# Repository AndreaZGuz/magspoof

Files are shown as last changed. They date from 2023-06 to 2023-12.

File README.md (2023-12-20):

# MagSpoof By Electronic Cats

# What is MagSpoof?

**MagSpoof by Electronic Cats** is a device that can spoof/emulate any magnetic stripe or credit card. It can work "wirelessly", even on **standard magstripe/credit card readers**, by generating a strong electromagnetic field that emulates a traditional magnetic stripe card.

* Allows you to store all of your credit cards and magstripes in one device
* Works on traditional magstripe readers **wirelessly** (no NFC/RFID required)
* Can **disable** Chip-and-PIN (code not included)
* Correctly **predicts** Amex credit card numbers + expirations from previous card number (code not included)
* Supports all three magnetic stripe tracks, and even supports Track 1+2 simultaneously
* Easy to build using Arduino or other common parts

MagSpoof can be used as a traditional credit card and simply store all of your credit cards (and with modification, can technically disable chip requirements) in various impressive and exciting form factors, or can be used for security research in any area that would traditionally require a magstripe, such as readers for credit cards, drivers licenses, hotel room keys, automated parking lot tickets, etc.

**Note**: The Chip-and-PIN and Amex information is **not** implemented and using MagSpoof requires you to have/own the magstripes that you wish to emulate. Simply having a credit card number and expiration is not enough to perform transactions. MagSpoof **does** allow you to perform research in other areas of magstripes, microcontrollers, and electromagnetism, as well as learn about and create your own devices similar to other existing, commercial technologies such as <a href="http://www.samsung.com/us/support/answer/ANS00043865/997410383/">Samsung MST</a> and <a href="https://onlycoin.com/">Coin</a>.</p>

### ⚠️ Disclaimer ⚠️
MagSpoof is a wireless penetration testing tool intended solely for use in authorized security audits, where such usage is permitted by applicable laws and regulations. Before utilizing this tool, it is crucial to ensure compliance with all relevant legal requirements and obtain appropriate permissions from the relevant authorities.

It is essential to note that the board does not provide any means or authorization to utilize credit cards or engage in any financial transactions that are not legally authorized. Electronic Cats holds no responsibility for any unauthorized use of the tool or any resulting damages.

-----

# Based in work of Samy Kamkar

**Point of Contact:** [@SamyKamkar](https://twitter.com/samykamkar)

You can see more of my projects at <http://samy.pl> or contact me at <code@samy.pl>.

------

# Wiki and Getting Started 

------
# License

Electronic Cats invests time and resources in providing this open-source design. Please support Electronic Cats and open-source hardware by purchasing products from Electronic Cats!

Designed by Electronic Cats.

Firmware released under an GNU AGPL v3.0 license. See the LICENSE file for more information.

Hardware released under an CERN Open Hardware Licence v1.2. See the LICENSE_HARDWARE file for more information.

Electronic Cats is a registered trademark, please do not use if you sell these PCBs.

30 Octuber 2019

------

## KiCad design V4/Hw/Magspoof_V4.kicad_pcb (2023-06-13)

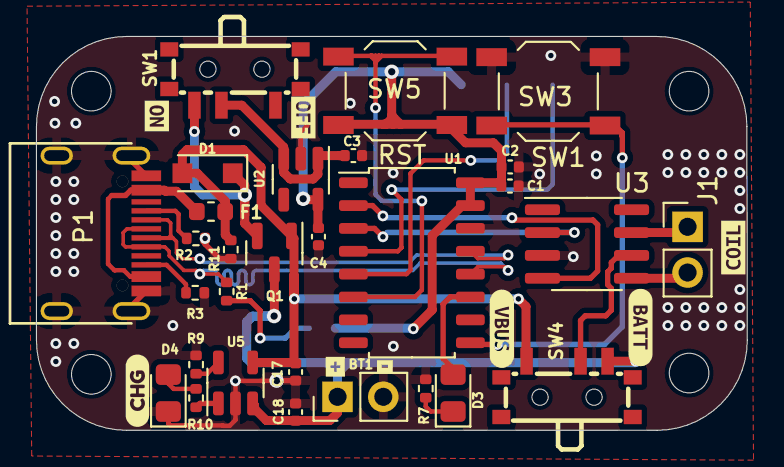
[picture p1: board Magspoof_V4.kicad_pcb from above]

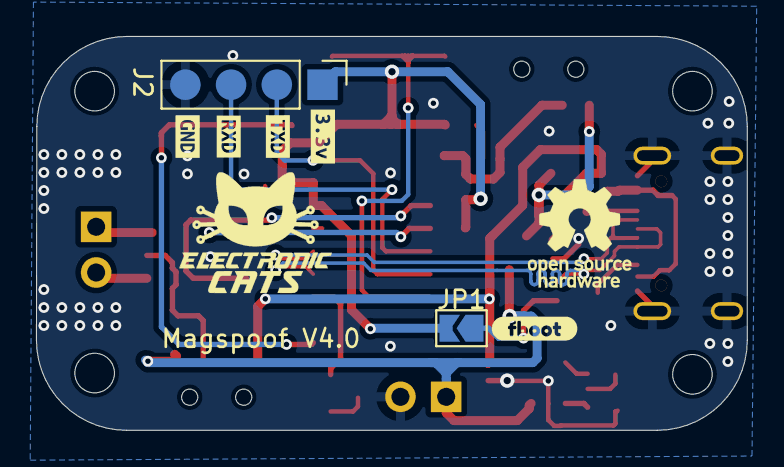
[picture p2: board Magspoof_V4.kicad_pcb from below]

Board: 2 copper layers, 39.5 x 21.9 mm, 48 parts (7 on the bottom side), 26 nets.

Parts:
BT1: Battery_Cell; PinHeader_1x02_P2.54mm_Vertical
C1, C2: 0.1uF; C_0402_1005Metric
C3, C4, C17, C18: 10uF; C_0402_1005Metric
D1: MBR120; D_SOD-123F
D3: Status; LED_0805_2012Metric_Pad1.15x1.40mm_HandSolder
D4: CHG; LED_0805_2012Metric_Pad1.15x1.40mm_HandSolder
F1: 0.5A; Fuse_0603_1608Metric
H1, H2, H3, H4: MountingHole; MountingHole_2.2mm_M2
J1: Coil; PinHeader_1x02_P2.54mm_Vertical
J2: SWD; PinHeader_1x04_P2.54mm_Vertical
JP1: boot; SolderJumper-2_P1.3mm_Open_TrianglePad1.0x1.5mm
P1: USB_C_Plug_USB2.0; C393939
Q1: DMG3415U-7; SOT-23
R1: 20K; R_0402_1005Metric
R2, R3, R9: 5.1k; R_0402_1005Metric
R7: 180R; R_0402_1005Metric
R10: 470; R_0402_1005Metric
R11: 100K; R_0402_1005Metric
SW1: ON; SW-SMD_SSSS811101
SW3: S1; SW_SPST_TL3342
SW4: SOURCE MAG; SW-SMD_SSSS811101
SW5: RESET; SW_SPST_TL3342
U1: CH552G; SOP-16_4.55x10.3mm_P1.27mm
U2: AP2112K-3.3; SOT-23-5
U3: TC4424; SOIC-8_3.9x4.9mm_P1.27mm
U5: MCP73831; SOT-23-5
kibuzzard-6435F1C7: G***; kibuzzard-6435F1C7
kibuzzard-6435F3C4: G***; kibuzzard-6435F3C4
kibuzzard-6435F22E: G***; kibuzzard-6435F22E
kibuzzard-6436E8D1: G***; kibuzzard-6436E8D1
kibuzzard-6436E8D8: G***; kibuzzard-6436E8D8
kibuzzard-6436EA37: G***; kibuzzard-6436EA37
kibuzzard-6436EA46: G***; kibuzzard-6436EA46
kibuzzard-6436EF9F: G***; kibuzzard-6436EF9F
kibuzzard-6436EF98: G***; kibuzzard-6436EF98
kibuzzard-64629FC5: G***; kibuzzard-64629FC5
kibuzzard-64629FDC: G***; kibuzzard-64629FDC
kibuzzard-64665C6A: G***; kibuzzard-64665C6A
kibuzzard-64665C9F: G***; kibuzzard-64665C9F

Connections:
+3V3: C1.1, C2.1, C4.1, J2.1, JP1.2 (B), SW5.2, U1.15 (VCC), U1.16 (V33), U2.5 (VOUT)
+BATT: BT1.1 (+), C18.1, Q1.3 (D), SW4.3 (C), U5.3 (VBAT)
/D+: P1.A6 (D+), R1.2, U1.12 (P3.6)
/D-: P1.A7 (D-), U1.13 (P3.7)
/IN_A: U1.2 (P1.4), U3.4 (IN_B)
/IN_B: U1.3 (P1.5), U3.2 (IN_A)
/LED: D3.2 (A), U1.11 (P3.4)
/Out_A: J1.1, U3.7 (OUT_A)
/Out_B: J1.2, U3.5 (OUT_B)
/RST: SW5.1, U1.6 (RST)
/RXD: J2.3, U1.4 (P1.6)
/SW1: SW3.2, U1.9 (P1.1)
/TXD: J2.2, U1.5 (P1.7)
GND: BT1.2 (-), C1.2, C2.2, C3.2, C4.2, C17.2, C18.2, D4.1 (K), J2.4, P1.A1 (GND), P1.S1 (SHIELD), R2.1, R3.1, R7.2, R9.2, R11.2, SW3.1, U1.14 (GND), U2.2 (GND), U3.3 (GND), U5.2 (VSS)
unnamed: D1.1 (K), Q1.2 (S), SW1.3 (A)
unnamed: D3.1 (K), R7.1
unnamed: D4.2 (A), R10.2
unnamed: F1.1, P1.A4 (VBUS)
unnamed: JP1.1 (A), R1.1
unnamed: P1.A5 (CC), R2.2
unnamed: P1.B5 (VCONN), R3.2
unnamed: C3.1, SW1.2 (B), U2.1 (VIN), U2.3 (EN)
unnamed: SW4.2 (B), U3.6 (VDD)
unnamed: R9.1, U5.5 (PROG)
unnamed: R10.1, U5.1 (STAT)
VBUS: C17.1, D1.2 (A), F1.2, Q1.1 (G), R11.1, SW4.1 (A), U5.4 (VDD)

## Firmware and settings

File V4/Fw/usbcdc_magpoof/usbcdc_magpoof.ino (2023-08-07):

/************************************************************
  Magspoof V4
  Modified version by Eduardo Contreras
  for Electronic Cats
  
  Original code by Samy Kamk  r (http://samy.pl/magspoof/)
  
  This example demonstrates how to use Magspoof v3 by Electronic Cats
  https://github.com/ElectronicCats/magspoof
  
  Development environment specifics:
  IDE: Arduino 1.8.9
  Hardware Platform:
  Magspoof V4
  
  This code is beerware; if you see me (or any other Electronic Cats
  member) at the local, and you've found our code helpful,
  please buy us a round!
  Distributed as-is; no warranty is given.
*/


#define PINS_PORT 1
#define PIN_A_BIT 4
#define PIN_B_BIT 5

#define BUTTON_PIN 11
#define LED 34
#define CLOCK_US 500

#define BETWEEN_ZERO 53 // 53 zeros between track1 & 2

#define TRACKS 2
#define MAX 80
//This is a fairly large array, store it in external memory with keyword __xdata
__xdata char recvStr[MAX];
uint8_t recvStrPtr = 0;
bool stringComplete = false;
uint16_t echoCounter = 0;

// consts get stored in flash as we don't adjust them
char tracks[2][MAX]= {
"%B123456781234567^LASTNAME/FIRST^YYMMSSSDDDDDDDDDDDDDDDDDDDDDDDDD?\0", // Track 1
";123456781234567=112220100000000000000?\0" // Track 2
};

char revTrack[41];

int sublen[] = {
  32, 48, 48 };

int bitlen[] = {
  7, 5, 5 };

unsigned int curTrack = 0;
uint8_t dir;

void blink(uint8_t pin, int msdelay, int times){
  for (uint8_t i = 0; i < times; i++){
    digitalWrite(pin, HIGH);
    delay(msdelay);
    digitalWrite(pin, LOW);
    delay(msdelay);
  }
}

// send a single bit out
void playBit(int sendBit){
  dir ^= 1;
  digitalWriteFast(PINS_PORT,PIN_A_BIT, dir);
  digitalWriteFast(PINS_PORT,PIN_B_BIT, !dir);
  delayMicroseconds(CLOCK_US);

  if (sendBit){
    dir ^= 1;
    digitalWriteFast(PINS_PORT,PIN_A_BIT, dir);
    digitalWriteFast(PINS_PORT,PIN_B_BIT, !dir);
  }
  delayMicroseconds(CLOCK_US);

}

// when reversing
void reverseTrack(int track){
  int i = 0;
  track--; // index 0
  dir = 0;

  while (revTrack[i++] != '\0');
  i--;
  while (i--)
    for (int j = bitlen[track]-1; j >= 0; j--)
      playBit((revTrack[i] >> j) & 1);
}

// plays out a full track, calculating CRCs and LRC
void playTrack(int track){
  int tmp, crc, lrc = 0;
  track--; // index 0
  dir = 0;

  // enable H-bridge and LED
  //digitalWrite(ENABLE_PIN, HIGH);

  // First put out a bunch of leading zeros.
  for (int i = 0; i < 25; i++)
    playBit(0);

  //
  for (int i = 0; tracks[track][i] != '\0'; i++)
  {
    crc = 1;
    tmp = tracks[track][i] - sublen[track];

    for (int j = 0; j < bitlen[track]-1; j++)
    {
      crc ^= tmp & 1;
      lrc ^= (tmp & 1) << j;
      playBit(tmp & 1);
      tmp >>= 1;
    }
    playBit(crc);
  }

  // finish calculating and send last "byte" (LRC)
  tmp = lrc;
  crc = 1;
  for (int j = 0; j < bitlen[track]-1; j++)
  {
    crc ^= tmp & 1;
    playBit(tmp & 1);
    tmp >>= 1;
  }
  playBit(crc);

  // if track 1, play 2nd track in reverse (like swiping back?)
  if (track == 0)
  {
    // if track 1, also play track 2 in reverse
    // zeros in between
    for (int i = 0; i < BETWEEN_ZERO; i++)
      playBit(0);

    // send second track in reverse
    reverseTrack(2);
  }

  // finish with 0's
  for (int i = 0; i < 5 * 5; i++)
    playBit(0);

  digitalWriteFast(PINS_PORT,PIN_A_BIT, LOW);
  digitalWriteFast(PINS_PORT,PIN_B_BIT, LOW);
}

// stores track for reverse usage later
void storeRevTrack(int track){
  int i, tmp, crc, lrc = 0;
  track--; // index 0
  dir = 0;

  for (i = 0; tracks[track][i] != '\0'; i++)
  {
    crc = 1;
    tmp = tracks[track][i] - sublen[track];

    for (int j = 0; j < bitlen[track]-1; j++)
    {
      crc ^= tmp & 1;
      lrc ^= (tmp & 1) << j;
      tmp & 1 ?
        (revTrack[i] |= 1 << j) :
        (revTrack[i] &= ~(1 << j));
      tmp >>= 1;
    }
    crc ?
      (revTrack[i] |= 1 << 4) :
      (revTrack[i] &= ~(1 << 4));
  }

  // finish calculating and send last "byte" (LRC)
  tmp = lrc;
  crc = 1;
  for (int j = 0; j < bitlen[track]-1; j++)
  {
    crc ^= tmp & 1;
    tmp & 1 ?
      (revTrack[i] |= 1 << j) :
      (revTrack[i] &= ~(1 << j));
    tmp >>= 1;
  }
  crc ?
    (revTrack[i] |= 1 << 4) :
    (revTrack[i] &= ~(1 << 4));

  i++;
  revTrack[i] = '\0';
}

void s_print(char *s) {
  for(int i = 0; i < MAX ; i++) {
      USBSerial_print(s[i]);
      if(s[i] == '?')break;
    }
  USBSerial_println();  
}

void dumpEEPROM() {
  USBSerial_println("DataFlash Dump:");
  for (uint8_t i = 0; i < 2*MAX; i++) {
    char eepromData = eeprom_read_byte(i);
    USBSerial_print(eepromData);
  }
  USBSerial_println();
  USBSerial_flush();
}

void setup(){
  Serial0_begin(115200);
  pinMode(LED, OUTPUT);
  digitalWrite(LED,LOW);

  pinModeFast(PINS_PORT,PIN_A_BIT, OUTPUT);
  pinModeFast(PINS_PORT,PIN_B_BIT, OUTPUT);
  pinMode(BUTTON_PIN, INPUT_PULLUP);

  for (uint8_t i = 0; i < MAX; i++) {
    char eepromData = eeprom_read_byte(i);
    tracks[0][i] = eepromData;
    USBSerial_print(tracks[0][i]);
    if(tracks[0][i] == '?'){tracks[0][i + 1] = '\0';break;}
  }

  for (uint8_t i = MAX; i < 2*MAX; i++) {
    char eepromData = eeprom_read_byte(i);
    tracks[1][i - MAX] = eepromData;
    USBSerial_print(tracks[1][i - MAX]);
    if(tracks[1][i - MAX] == '?'){tracks[1][i + 1 - MAX] = '\0';break;}
  }

  storeRevTrack(TRACKS);
      
  USBSerial_println();
  USBSerial_flush();
  USBSerial_println("MagSpoof test");

}

void loop(){
    if (digitalRead(BUTTON_PIN) == 0){
      USBSerial_println("MagSpoof");
      digitalWrite(LED,HIGH);
      playTrack(1 + (curTrack++ % 2));
      delay(500);
      digitalWrite(LED,LOW);
      s_print(tracks[0]);
      s_print(tracks[1]);
      delay(1000);
    }

  while (USBSerial_available()) {
    char serialChar = USBSerial_read();
    if ((serialChar == '\n') || (serialChar == '\r') ) {
      recvStr[recvStrPtr] = '\0';
      if (recvStrPtr > 0) {
        stringComplete = true;
        break;
      }
    } else {
      recvStr[recvStrPtr] = serialChar;
      recvStrPtr++;
      if (recvStrPtr == MAX) {
        recvStr[recvStrPtr] = '\0';
        stringComplete = true;
        break;
      }
    }
  }

  if (stringComplete) {

    if(recvStr[0] == 's') {

      USBSerial_println("...to EEPROM");
      //strcpy(tracks[0], recvStr);
      
      for(uint8_t i = 0; i < MAX ; i++) {
        eeprom_write_byte(i, tracks[0][i]);
        if(tracks[0][i] == '?'){
          eeprom_write_byte(i + 1, '\0');
          USBSerial_println("? found");
          break;
        }
      }
      
      for(uint8_t i = MAX; i < 2*MAX ; i++) {
        eeprom_write_byte(i, tracks[1][i - MAX]);
        if(tracks[1][i] == '?'){
          eeprom_write_byte(i + 1, '\0');
          USBSerial_println("? found");
          break;
        }
      }
      dumpEEPROM(); 
    }
    
    if(recvStr[0] == '%') {
      for(uint8_t i = 0; i < MAX ; i++) {
        tracks[0][i] = recvStr[i];
        if(recvStr[i] == '?'){
          USBSerial_println("? found");
          {tracks[0][i + 1] = '\0';break;}
        }
      }
    storeRevTrack(TRACKS);
    }

    if(recvStr[0] == ';') {

      for(uint8_t i = 0; i < MAX ; i++) {
        tracks[1][i] = recvStr[i];
        if(recvStr[i] == '?'){
          USBSerial_println("? found");
          {tracks[1][i + 1] = '\0';break;}
        }
      }
    storeRevTrack(TRACKS);  
    }

    if(recvStr[0] == 'p') {
      
      USBSerial_println("MagSpoof");
      digitalWrite(LED,HIGH);
      playTrack(1 + (curTrack++ % 2));
      delay(500);
      digitalWrite(LED,LOW);
      s_print(tracks[0]);
      s_print(tracks[1]);
      delay(1000);
 
    }    


    USBSerial_print("ECHO:");
    USBSerial_println(recvStr);

    s_print(tracks[0]);
    s_print(tracks[1]);  
    USBSerial_println();

    stringComplete = false;
    recvStrPtr = 0;

    USBSerial_flush();
  }
}

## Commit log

2023-05-11 add lcsc components to BOM
    [Magspoof_V4.kicad_sch]
2023-05-15 Change components for JLCPCB
    [Magspoof_V4.kicad_sch]
2023-05-15 change footprint of SW1,4, and F1 and routing
    [Magspoof_V4.kicad_pcb, Magspoof_V4.kicad_sch]
2023-05-15 change SW1 and SW4 for stocks
    [Magspoof_V4.csv, Magspoof_V4.kicad_pcb, Magspoof_V4.kicad_sch]
2023-05-18 Update labels
    [Magspoof_V4.kicad_pcb]
2023-05-18 change DFN-8 to SOIC-8 TC4424 and add 3d model of SW1,4
    [Magspoof_V4.kicad_pcb, Magspoof_V4.kicad_sch]
2023-05-19 Update BOM
    [Magspoof_V4.kicad_sch]
2023-06-05 fix serigraphy "SW1"for "RST"
    [Magspoof_V4.kicad_pcb]
2023-06-13 Update BOM (jlcpcb components)
    [Magspoof_V4.kicad_sch]
2023-12-15 Update README.md
    Adding: wiki button
